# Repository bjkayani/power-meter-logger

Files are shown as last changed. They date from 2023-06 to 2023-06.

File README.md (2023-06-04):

# Power Meter Logger

Modify off the shelf power meters from Peacefair to pull the power data and log it using a microcontroller. 



## Supported Power Meters

- PZEM-031 (V4.0)
- PZEM-051 (V5.0)

## Supported Boards

- ESP32-WROOM

## Guide

1. Buy the above mentioned power meter.
2. Open up the back cover and solder four wires to the connections in the diagram below. (PZEM-051 (V5.0) has convenient testpoints)
3. 3D print the backplate.
4. Solder the wires to a 4 pin female header and push it in the new back plate. 
5. Label the pinout on the back of the cover for later.
6. Hot glue the connections and close up the back cover.
7. Connect to the pins of the microcontroller as specified in the code. 
8. Flash the code using Arduino IDE. 
9. Wire up the power meter as shown in its manual or original back plate.
10. The micrcontroller should be spitting out the data on the serial console. 

<br>



<br>

[Blog Post](https://badar.tech/2023/06/03/power-meter-data-logging/)

## Future Work
- Convert code example to a library
- Add support for more power meters
- Add support for more dev boards/microcontrollers

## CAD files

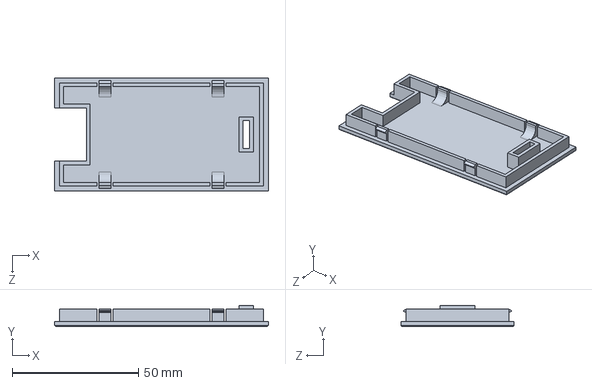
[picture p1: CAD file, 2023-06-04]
CAD/power meter back panel.SLDPRT
84.7 x 8.50 x 44.8 mm

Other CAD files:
CAD/power meter back panel v2.STL

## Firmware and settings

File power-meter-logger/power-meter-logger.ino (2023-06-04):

/**
 * Power Meter Logger
 * Author: Badar Jahangir Kayani
 * Date: 6/3/2023
 * Email: badarjahangir@gmail.comap
 * 
 * Read data from the Peacefair power module display driver and decode it to log
 * the voltage, current, power and energy.
 *  
 * Tested on ESP32-WROOM dev board.
 * 3.3V logic and interrupt capability required on CLK_PIN and CS_PIN
 * Display driver: TM1621B
 * Datasheet link: https://datasheet.lcsc.com/lcsc/2203031730_TM-Shenzhen-Titan-Micro-Elec-TM1621B_C2980111.pdf
 */

// Pin definitions
#define CS_PIN 19
#define CLK_PIN 18
#define DATA_PIN 5

// Data read stuff
#define BUFFER_SIZE 32
volatile uint32_t read_buffer[BUFFER_SIZE];
volatile uint8_t buffer_idx = 0;  // Packet read index
volatile uint8_t read_digit = 0;  // Bit read index (within a packet)
uint32_t data_buffer[16]; // Store the entire packet transmission sequence

// Data decoding look up table
uint8_t data_digit_lut_1[2][10] = {{0, 1, 2, 3, 4, 5, 6, 7, 8, 9},
                                  {117, 5, 83, 23, 39, 54, 118, 21, 119, 55}};

uint8_t data_digit_lut_2[2][10] = {{0, 1, 2, 3, 4, 5, 6, 7, 8, 9},
                                  {125, 5, 94, 79, 39, 107, 123, 69, 127, 111}};

/**
 * @brief ISR for the clock signal
 * Read the bit from the data pin and stuff it in the packet byte 
 * at the correct location to form the packet value one bit at a time
 */
void clock_isr() {
  read_buffer[buffer_idx] |= (digitalRead(DATA_PIN) << (16-read_digit));
  read_digit++;
}

/**
 * @brief ISR for the select signal
 * Select signal signifies start or end of packet transmision.
 */
void select_isr() {
  // Enable data reading when CS is pulled low
  if (!digitalRead(CS_PIN)) {
    read_digit = 0;
    read_buffer[buffer_idx] = 0;
    attachInterrupt(CLK_PIN, clock_isr, RISING);
  } else { // disable reading when its pulled high
    detachInterrupt(CLK_PIN);
    if (++buffer_idx >= BUFFER_SIZE) { buffer_idx = 0; }
  }
}

/**
 * @brief Process the read buffer to extract a single tranmission sequence
 * 
 * The display driver has 32 nibbles of memory that are written to control what
 * is displayed on the display. The power meter sends 16 packets of data, each with
 * the following structure:
 * 
 * | 3 bit Packet Type | 6 bit Memory Address | 4 bit Data | 4 bit Data |
 * 
 * Each packet has two data nibbles hence it sends 16 total packets to write to the 
 * entire memory. Each packet is 17 bit long. 
 * 
 * We can use the memory address value to verify that we read the data correctly,
 * then get the value of the data and store it in the read buffer. Since each packet
 * corresponds to one digit, I save the two nibbles as a single number. 
 * 
 * @return true Data processing was successful
 * @return false Data processing failed
 */
bool process_data_buffer(){
  uint32_t addr = 0;
  uint32_t cmd = 0;
  uint32_t expected_addr = 0;
  bool  data_start = false;
  uint8_t data_idx = 0;
  bool success = false;

  // Iterate over the entire read buffer
  for (int i = 0; i < BUFFER_SIZE; i++) {

    // Read and verify that the packet type is correct
    cmd = (read_buffer[i] & 0x0001C000) >> 14;

    if(cmd == 5){
      // Extract packet address
      addr = (read_buffer[i] & 0x00003F00) >> 8;
      // Check for the first address and set boolean to continue reading
      if (addr == 0){data_start = true;}

      if(data_start){
        // Validate each packet address
        if(addr != expected_addr){
          success = false;
          break;
        }

        expected_addr += 2;

        // Store the data value from each packet
        if (addr <= 14){  // First 8 packets 
          data_buffer[data_idx] = read_buffer[i] & 0x00000077;
        } else {  // Last 8 packets
          data_buffer[data_idx] = read_buffer[i] & 0x000000FF;
        }
        
        // Serial.print(addr);
        // Serial.print(":");
        // Serial.println(data_buffer[data_idx], DEC);
        data_idx++;

        // Break when the entire sequence has been read
        if(addr == 30){
          success = true;
          break;
        }
      }
    }
  }
  return success;
}

/**
 * @brief Get the voltage from the data buffer
 * 
 * @return float Voltage in volts
 */
float get_voltage(){
  if(!process_data_buffer()){
    return -1.0; 
  }

  float voltage_f = 0.0;
  uint32_t voltage = 0;

  for(int i=0; i < 4; i++){
    for(int j=0; j<10; j++){
      if(data_buffer[i]==data_digit_lut_1[1][j]){
        // Stuff the voltage digits in the correct unit location
        voltage += data_digit_lut_1[0][j] * pow(10, 3-i);
      }
    }
  }

  // Convert to volts
  voltage_f =  voltage / 100.0;;

  return voltage_f;
}

/**
 * @brief Get the current from the data buffer
 * 
 * @return float Current in amps
 */
float get_current(){
  if(!process_data_buffer()){
    return -1.0; 
  }

  float current_f = 0;
  uint32_t current = 0;

  for(int i=4; i < 8; i++){
    for(int j=0; j<10; j++){
      if(data_buffer[i]==data_digit_lut_1[1][j]){
        // Stuff the current digits in the correct unit location
        current += data_digit_lut_1[0][j] * pow(10, 7-i);
      }
    }
  }

  // Convert to amps
  current_f = current / 100.0;

  return current_f;
}

/**
 * @brief Get the power from the data buffer
 * 
 * @return float Power in Watts
 */
float  get_power(){
  if(!process_data_buffer()){
    return -1.0; 
  }

  uint32_t power = 0;
  float power_f = 0.0;

  for(int i=8; i < 12; i++){
    for(int j=0; j<10; j++){
      if((data_buffer[i]>>1)==data_digit_lut_2[1][j]){
        // Stuff the power digits in the correct unit location
        power += data_digit_lut_2[0][j] * pow(10, 11-i);
        
      }
    }
  }

  // Check if the decimal point is active or not and scale accordingly
  if((data_buffer[10] & 0x01)){
    power_f = (float)power / 10.0;
  } else {
    power_f = (float)power;
  }

  return power_f;
}

/**
 * @brief Get the energy from the data buffer
 * 
 * @return int32_t Energy in Wh
 */
int32_t get_energy(){
  if(!process_data_buffer()){
    return -1; 
  }

  uint32_t energy = 0;

  for(int i=12; i < 16; i++){
    for(int j=0; j<10; j++){
      if((data_buffer[i]>>1)==data_digit_lut_2[1][j]){
        // Stuff the energy digits in the correct unit location
        energy += data_digit_lut_2[0][j] * pow(10, 15-i);
        
      }
    }
  }

  // Check if the kilo digit is active or not and scale accordingly
  if((data_buffer[15] & 0x01)){
    energy = energy * 1000;
  }

  return energy;
}

/**
 * @brief Print the raw data buffer in binary
 * Use for debugging
 */
void print_raw(){
  process_data_buffer();

  for(int i=0; i < 16; i++){
    Serial.print(i);
    Serial.print(": ");
    Serial.println(data_buffer[i], BIN);
  }

}

void setup() {
  Serial.begin(115200);

  pinMode(CS_PIN, INPUT);
  pinMode(CLK_PIN, INPUT);
  pinMode(DATA_PIN, INPUT);

  // Attach interrupt on chip select pin to monitor rising and falling edges
  attachInterrupt(CS_PIN, select_isr, CHANGE);
}

void loop() {
  Serial.print("Voltage: ");
  Serial.print(get_voltage());
  Serial.print(" V  Current: ");
  Serial.print(get_current());
  Serial.print(" A  Power: ");
  Serial.print(get_power());
  Serial.print(" W  Energy: ");
  Serial.print(get_energy());
  Serial.println(" Wh");

  delay(1000);
}
